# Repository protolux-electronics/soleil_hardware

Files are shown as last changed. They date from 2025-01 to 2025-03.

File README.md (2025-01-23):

# Soleil Hardware

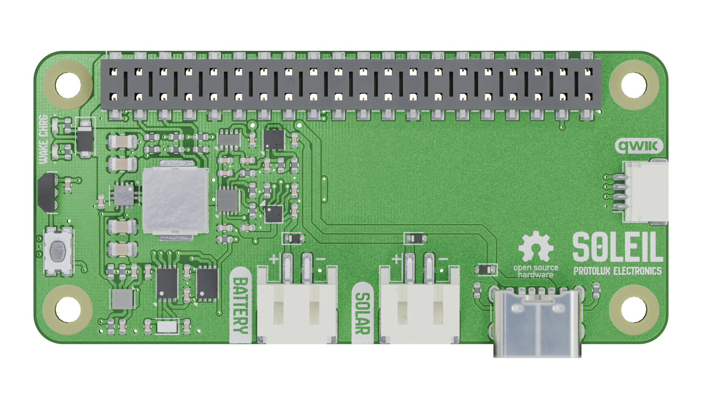
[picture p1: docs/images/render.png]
Soleil rendering

 
Soleil is a multi-functional solar charger and smart power management board for Rasbperry Pi. It has multiple use cases:

- **Off-grid**: power your project and simultaneously charge a single cell LiPo battery with a solar panel, up to 10W/16V.
- **Uninterruptible power supply**: Use a standard USB-C cable to power your Pi. In the case of a power outage, the power supply will automatically swap over to the backup battery without missing a beat.
- **Low power sleep mode**: completely cut off power to the Raspberry Pi for a duration of time. An onboard real-time clock will wake your project at the exact second you specify, up to one year in the future.

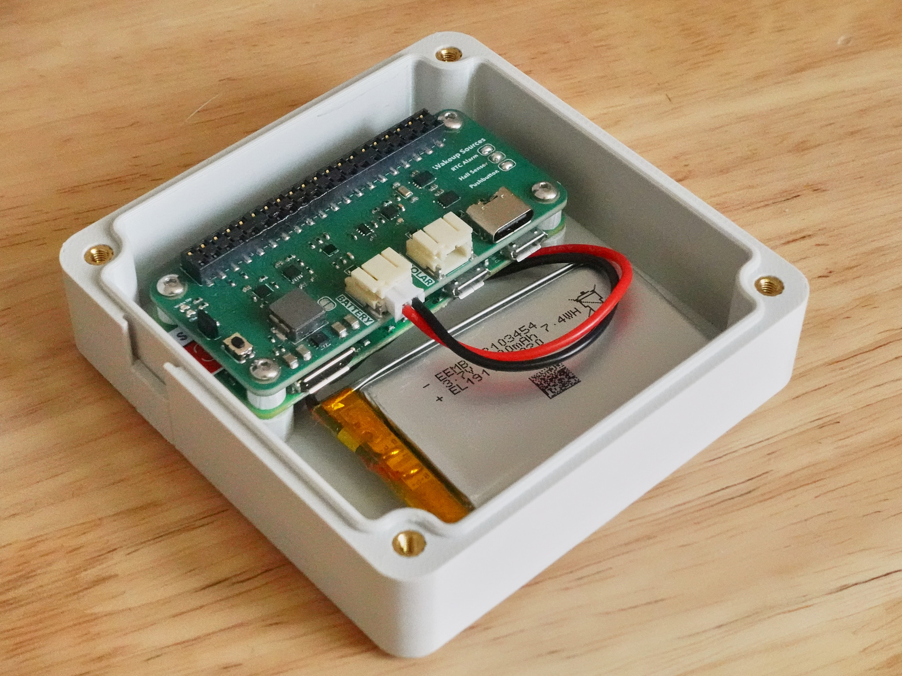
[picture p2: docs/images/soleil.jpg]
Soleil mounted in a 3D printed case


## Alternatives

Soleil takes inspiration from other boards on the market:

- [PiJuice Zero](https://uk.pi-supply.com/collections/pijuice/products/pijuice-zero)
- [WittyPi 4 Mini](https://www.uugear.com/product/witty-pi-4-mini/)
- [LiFePO4wered/Pi+](https://www.crowdsupply.com/silicognition/lifepo4wered-pi-plus)

Soleil is different, as it combines both the smart power management features with solar battery charging, up to 16V. In low power mode, Soleil only draws 15uA, making it a great choice for projects such as weather stations, IoT sensors, wildlife cameras, and more. Additionally, Soleil doesn't have a microcontroller onboard, and thus doesn't require firmware. It makes it just a little bit easier to hack on without requiring specialized programming hardware.

Additionally, Soleil is completely open hardware, build with KiCad. You can hack the hardware, modify the design to add your own sensors, or customize it to your liking. Supporting Soleil means supporting Open Source Hardware - an initiative that benefits all of us.

## Additional Features

Soleil includes a battery fuel gauge IC to get accurate state of charge estimations. There are also two manual wakeup sources - a pushbutton and a hall-effect switch. You may replace the hall effect switch with any open-drain sensor or circuit to trigger wakeup. Finally, Soleil features an ATECC608A security chip to provide first-class support for [NervesHub](https://nerves-hub.org), a firmware update management tool for Nerves-powered devices. 

See the block diagram below for an understanding of the connectivity of each of Soleil's components:

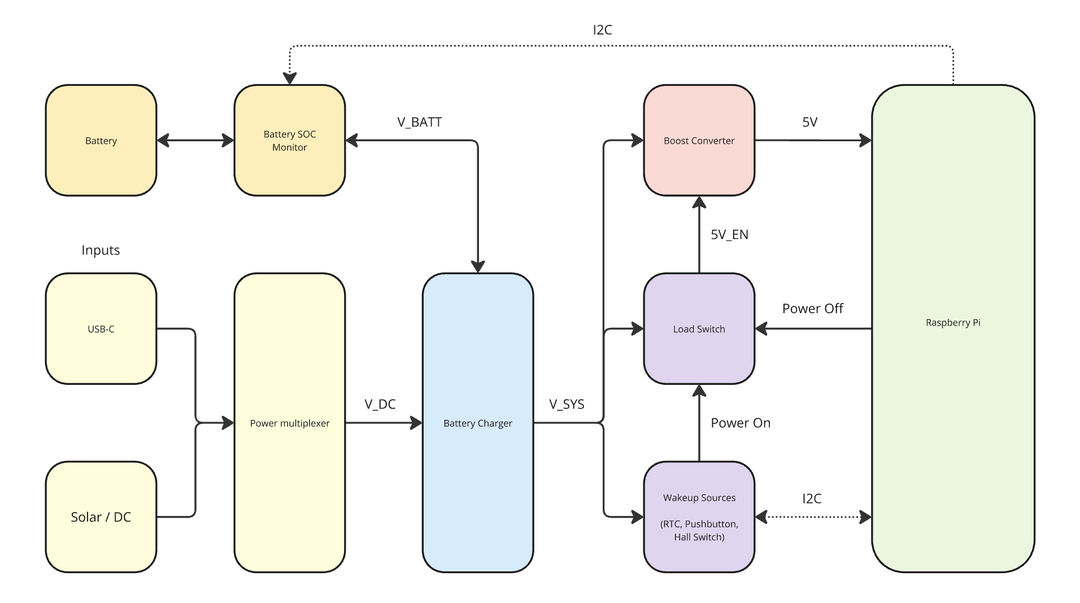
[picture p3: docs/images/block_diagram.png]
Block diagram


## Software

The official software library is available in the [Soleil repository](https://github.com/protolux-electronics/soleil). Soleil was specifically designed for use with the [Nerves Framework](https://nerves-project.org). See the [documentation](https://hexdocs.pm/soleil) for more information.

## Protolux Electronics

Soleil was designed by Protolux Electronics. We're a tiny team of passionate engineers, creatives, and designers based in Luxembourg.

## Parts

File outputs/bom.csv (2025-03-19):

Reference | Value | Footprint | Qty | DNP | LCSC | MPN
C1,C4 | 6p | Capacitor_SMD:C_0402_1005Metric | 2 |  | C437444 | GCM1555C1H6R0DA16D
C2,C3,C5,C6,C7,C8,C9,C10,C11 | 100n | Capacitor_SMD:C_0402_1005Metric | 9 |  | C71629 | GRM155R71C104KA88J
C12,C13,C14,C15 | 22u | Capacitor_SMD:C_0805_2012Metric | 4 |  | C98190 | CL21A226MOQNNNE
C16,C17,C18,C21,C24 | 1u | Capacitor_SMD:C_0402_1005Metric | 5 |  | C29266 | CL05A105KO5NNNC
C19,C20,C23 | 2u2 | Capacitor_SMD:C_0402_1005Metric | 3 |  | C72203 | GRM155R61E225ME15D
D1 | ESD5Z24 | Diode_SMD:D_SOD-523 | 1 |  | C23380859 | ESD5Z24
D2,D5 | RED | LED_SMD:LED_0402_1005Metric | 2 |  | C779449 | XZMDK68W-2
D3,D4 | ESD5Z6.0 | Diode_SMD:D_SOD-523 | 2 |  | C2890110 | ESD5Z6.0T1G
D6 | 500mV @ 2A | Diode_SMD:D_SOD-123F | 1 |  | C2972823 | S-LMBR340FT1G
J1,J4 | S2B-PH-SM4 | gworkman_connector:JST_PH_01x02_SMT_Horizontal | 2 |  | C295747 | S2B-PH-SM4-TB
J2 | Raspberry_Pi | gworkman_connector:RaspberryPi_low_profile_HAT_connector | 1 |  | C2685112 | FH-00339
J3 | USB4125-GF-A | Connector_USB:USB_C_Receptacle_GCT_USB4125-xx-x_6P_TopMnt_Horizontal | 1 |  | C2874565 | USB4125-GF-A
J5 | SM04B-SRSS-TB | Connector_JST:JST_SH_SM04B-SRSS-TB_1x04-1MP_P1.00mm_Horizontal | 1 |  | C160404 | SM04B-SRSS-TB
L1 | 1u5 | gworkman_device:L_Vishay_IHLP-2525 | 1 |  | C845020 | IHLP2525CZER1R5M01
R1,R2,R3,R4,R5,R8 | 5k1 | Resistor_SMD:R_0402_1005Metric | 6 |  | C105872 | RC0402FR-075K1L
R6,R7,R11,R16,R19,TH1 | 10k | Resistor_SMD:R_0402_1005Metric | 6 |  | C60490,C77131 | NCP15XH103F03RC,RC0402FR-0710KL
R9 | 750k | Resistor_SMD:R_0402_1005Metric | 1 |  | C137937 | RC0402FR-07750KL
R10 | 133k | Resistor_SMD:R_0402_1005Metric | 1 |  | C327374 | RC0402FR-07133KL
R13 | 13k | Resistor_SMD:R_0402_1005Metric | 1 |  | C138057 | RC0402FR-0713KL
R14,R20,R21 | 1M2 | Resistor_SMD:R_0402_1005Metric | 3 |  | C226867 | AC0402FR-071M2L
R15 | 200k | Resistor_SMD:R_0402_1005Metric | 1 |  | C114763 | RC0402FR-07200KL
R18 | 1k | Resistor_SMD:R_0402_1005Metric | 1 |  | C105637 | RC0402JR-071KL
SW1 | SW_Push | Button_Switch_SMD:SW_Push_1P1T_NO_CK_KMR2 | 1 |  | C221678 | KMR223GLFG
U1 | MCP7940N-xMNY | Package_DFN_QFN:DFN-8-1EP_3x2mm_P0.5mm_EP1.36x1.46mm | 1 |  | C623889 | MCP7940NT-I/MNY
U2 | XC6192B | gworkman_power:USP-8B06 | 1 |  | C2442364 | XC6192BANNER-G
U3 | LM66200 | gworkman_power:Texas_DRL0008A_SOT-583 | 1 |  | C3235556 | LM66200DRLR
U4 | ATECC608A-MAHDA | Package_DFN_QFN:DFN-8-1EP_3x2mm_P0.5mm_EP1.3x1.5mm | 1 |  | C616908 | ATECC608A-MAHDA-S
U5 | DRV5032FC | Package_TO_SOT_THT:TO-92Flat | 1 |  | C2866256 | DRV5032FCLPGM
U6 | MP3423 | gworkman_power:MPS_PowerQFN-14_2x2mm | 1 |  | C2682483 | MP3423GG-Z
U7 | BQ25185 | gworkman_power:Texas_DLH0010A_WSON-10 | 1 |  | C19725033 | BQ25185DLHR
U8 | TLV76701DRVx | Package_SON:WSON-6-1EP_2x2mm_P0.65mm_EP1x1.6mm_ThermalVias | 1 |  | C2863998 | TLV76701DRVR
U9 | BQ27427 | Package_BGA:Texas_DSBGA-9_1.62x1.58mm_Layout3x3_P0.5mm | 1 |  | C6075475 | BQ27427YZFR
Y1 | 32.768kHz | Crystal:Crystal_SMD_2012-2Pin_2.0x1.2mm | 1 |  | C3015107 | ECS-.327-7-12-TR

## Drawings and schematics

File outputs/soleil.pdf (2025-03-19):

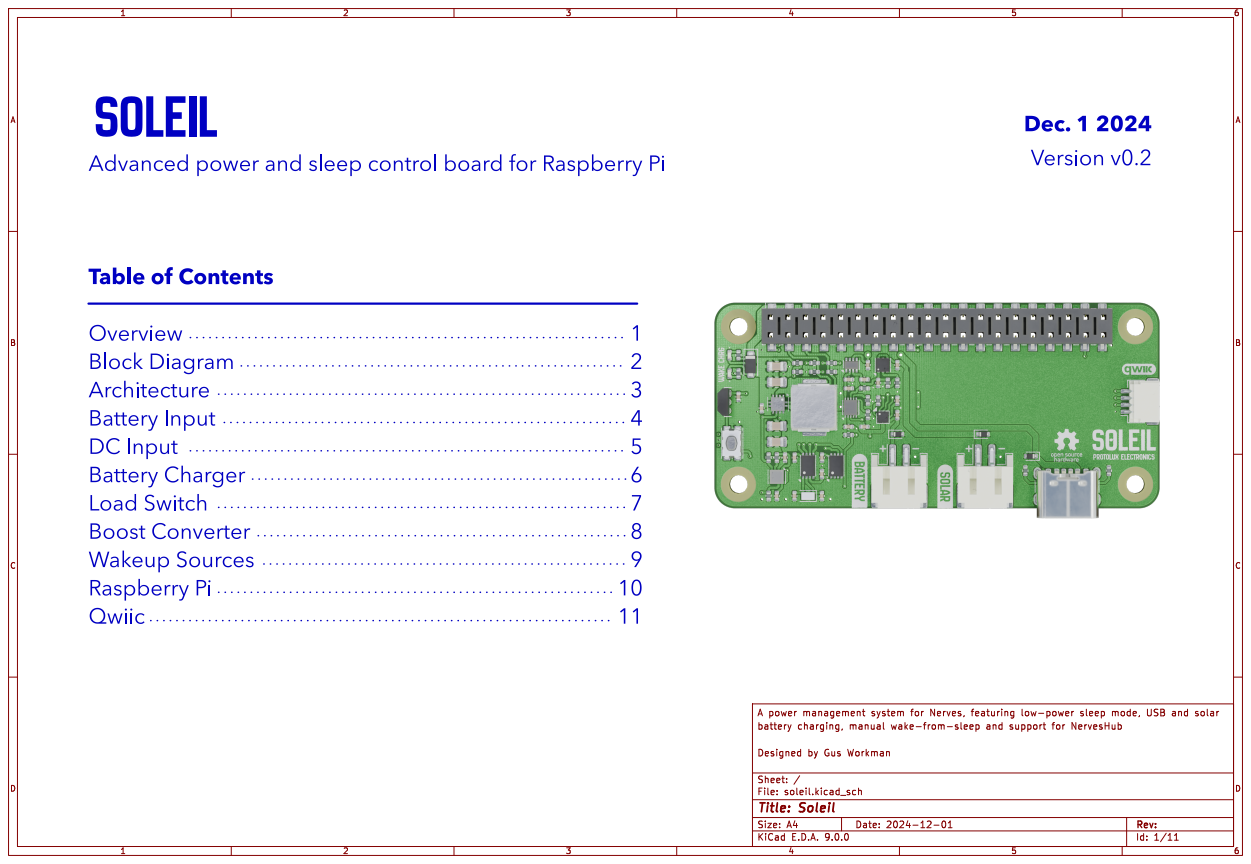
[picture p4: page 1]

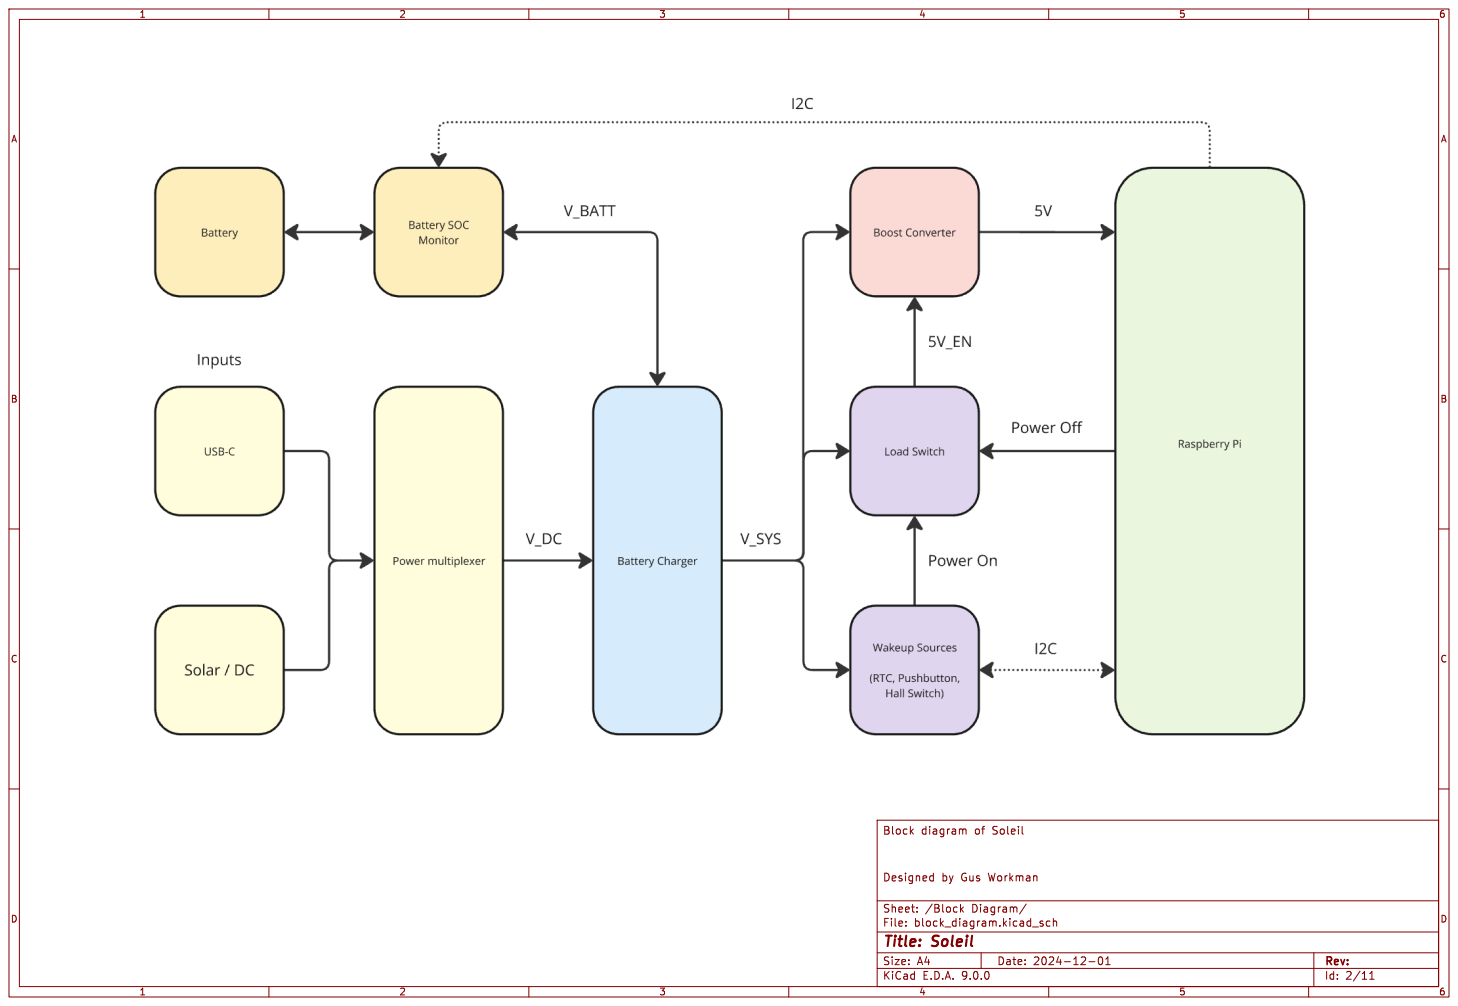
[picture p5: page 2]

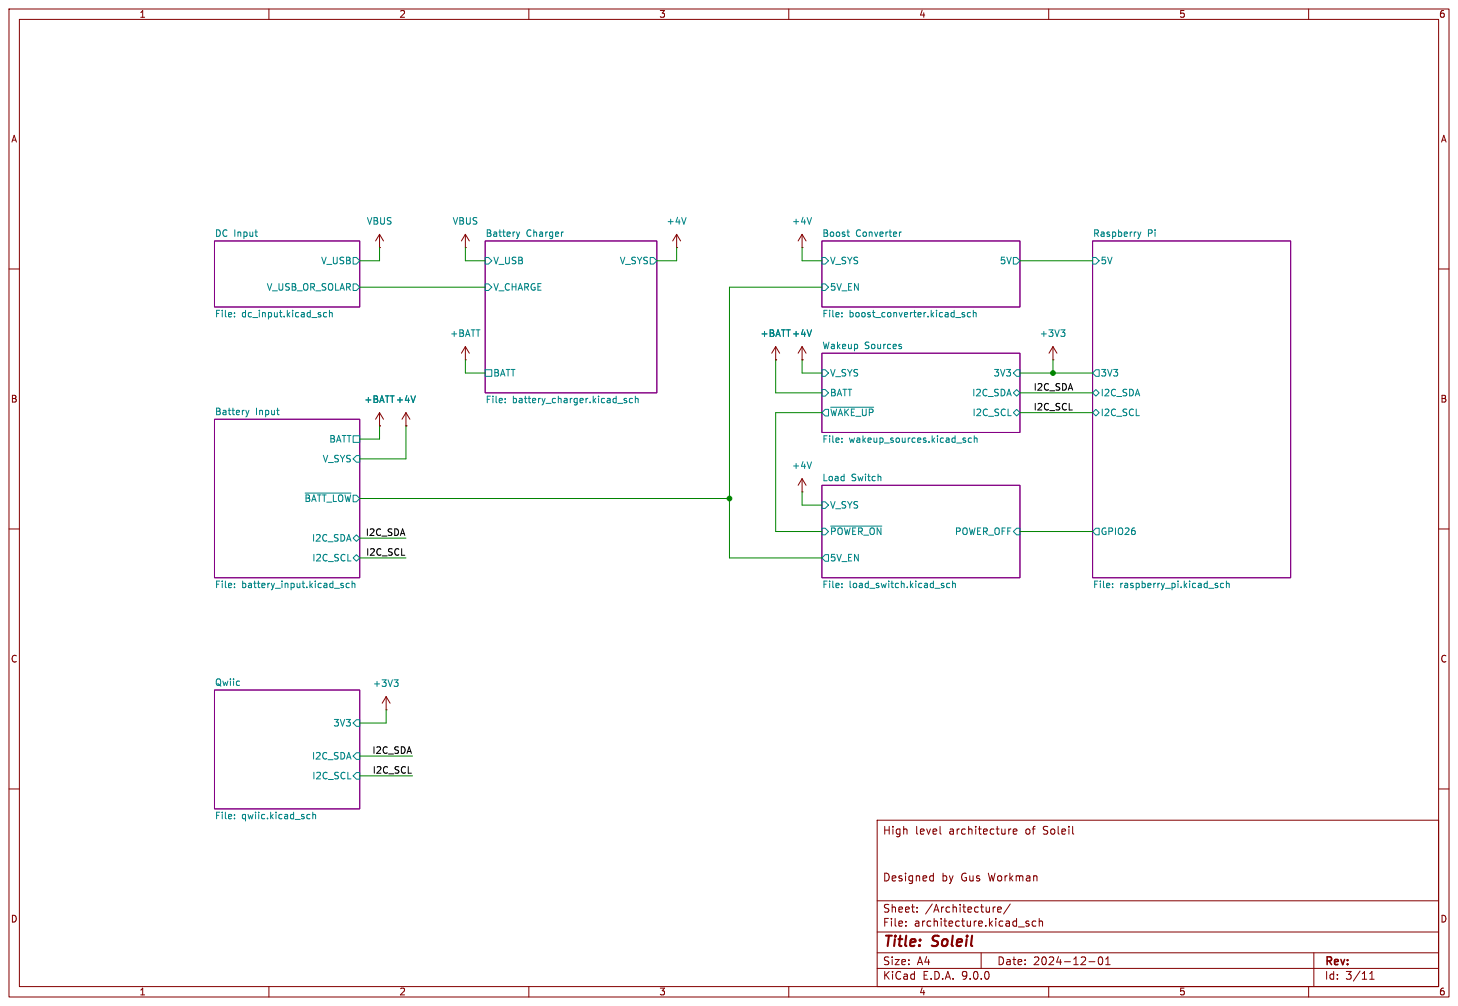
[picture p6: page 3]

Boost Converter File: boost_converter.kicad_sch ~{BATT_LOW} BATT

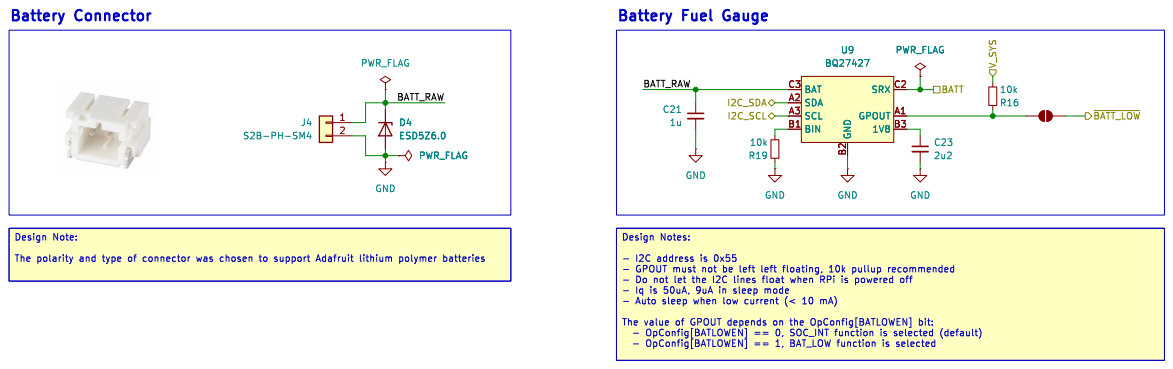
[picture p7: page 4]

- Do not let the I2C lines float when RPi is powered off - Iq is 50uA, 9uA in sleep mode

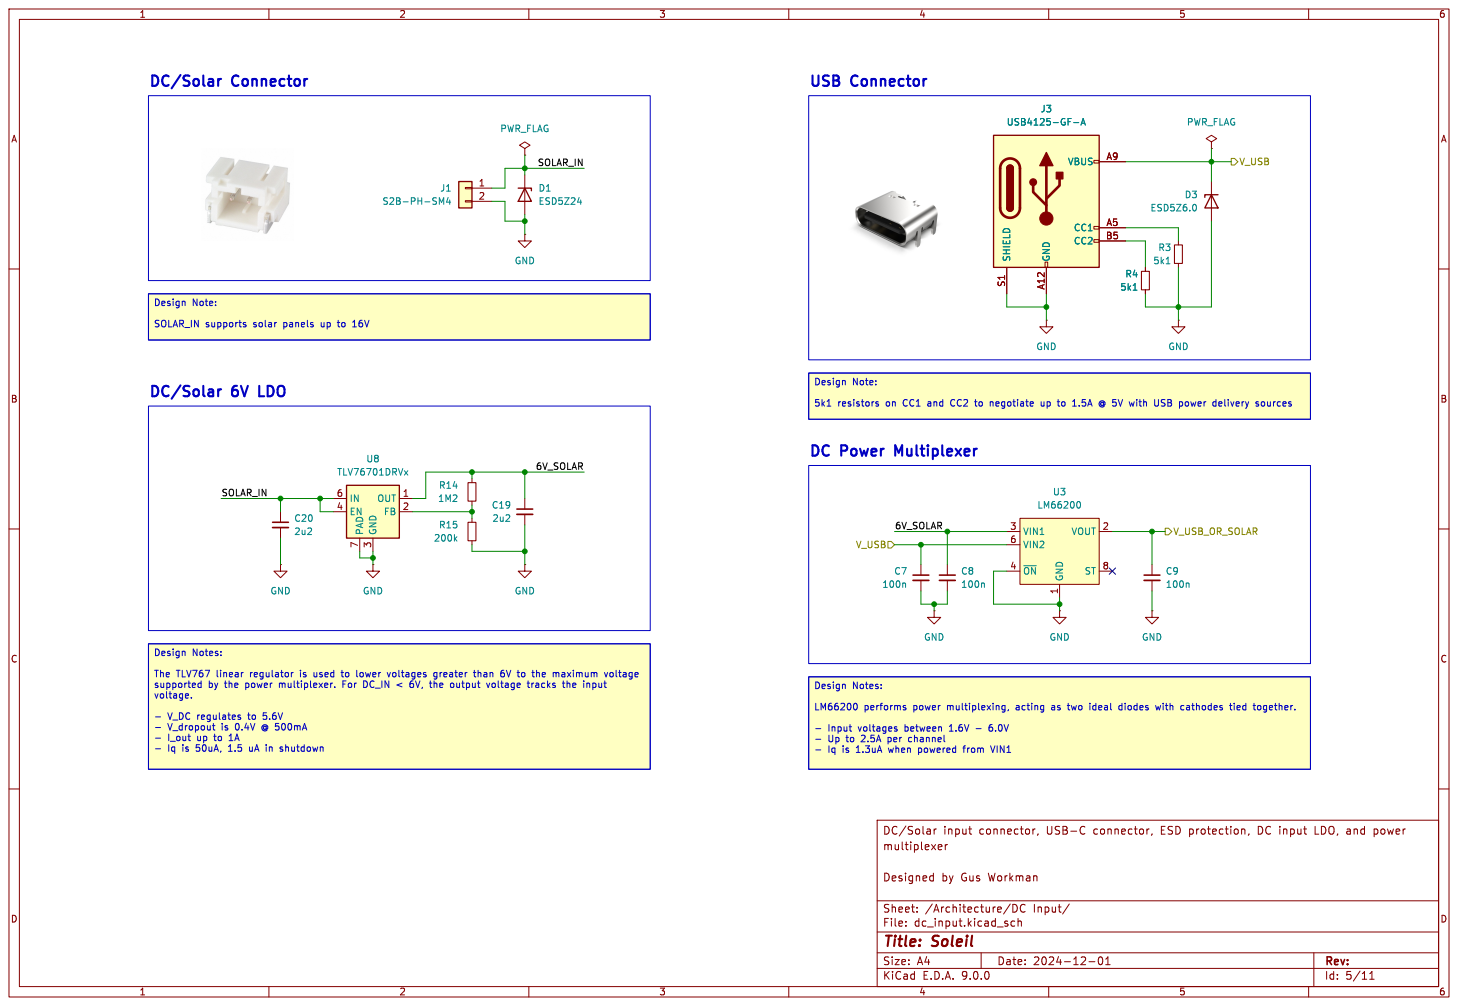
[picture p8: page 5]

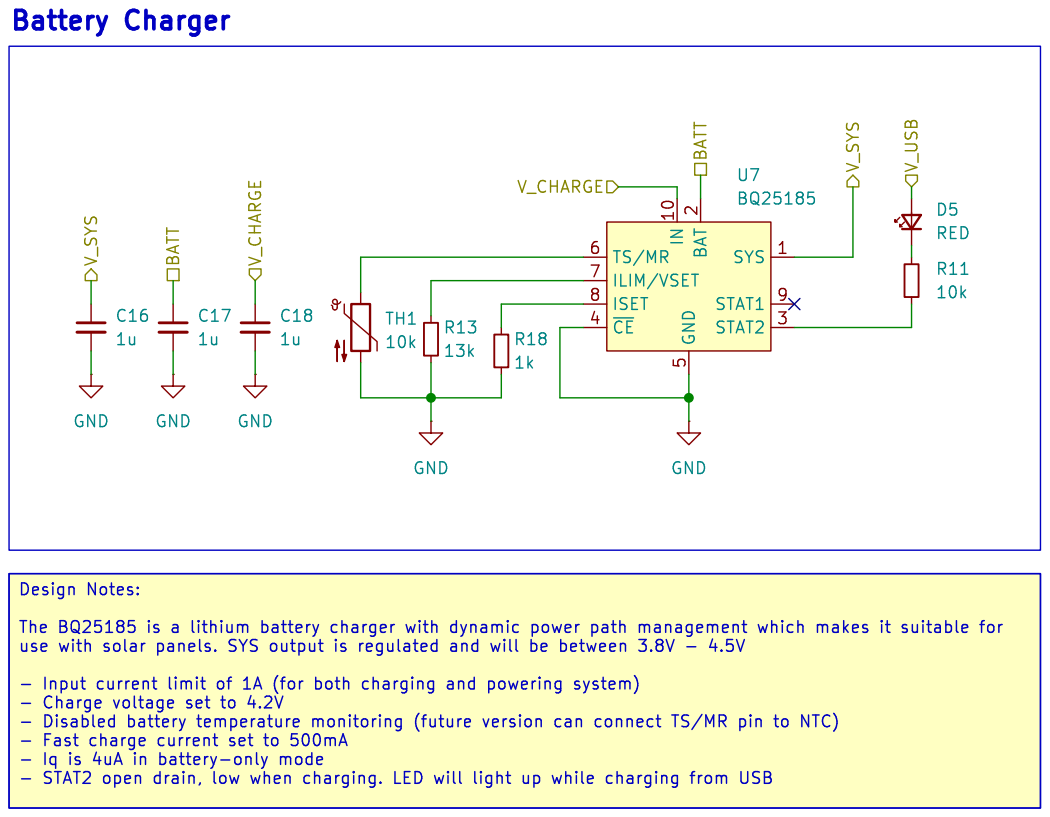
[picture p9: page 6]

- Charge voltage set to 4.2V
- Fast charge current set to 500mA

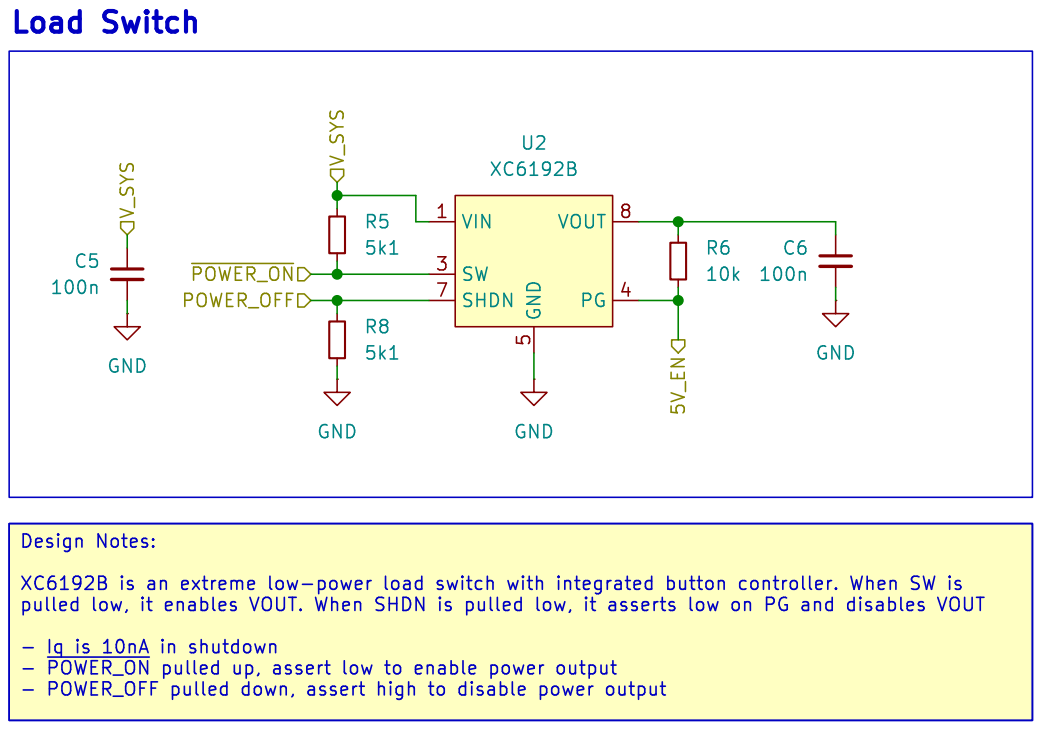
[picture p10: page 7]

- Iq is 10nA in shutdown

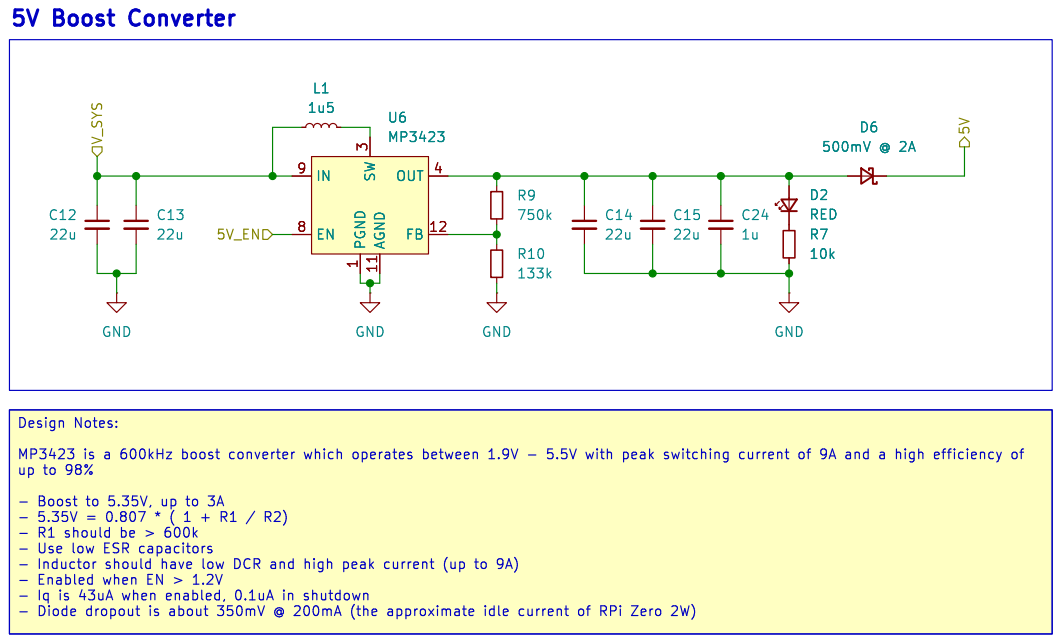
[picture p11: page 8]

3 AGND 11 OUT 4 FB 12 U6 MP3423 GND

- Boost to 5.35V, up to 3A
- R1 should be > 600k
- Use low ESR capacitors
- Enabled when EN > 1.2V
- Iq is 43uA when enabled, 0.1uA in shutdown

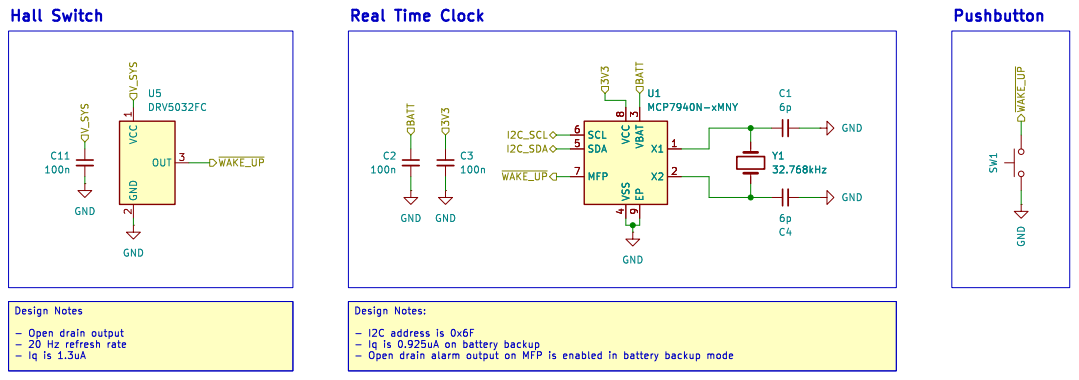
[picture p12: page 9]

- Open drain output - 20 Hz refresh rate

- Iq is 0.925uA on battery backup

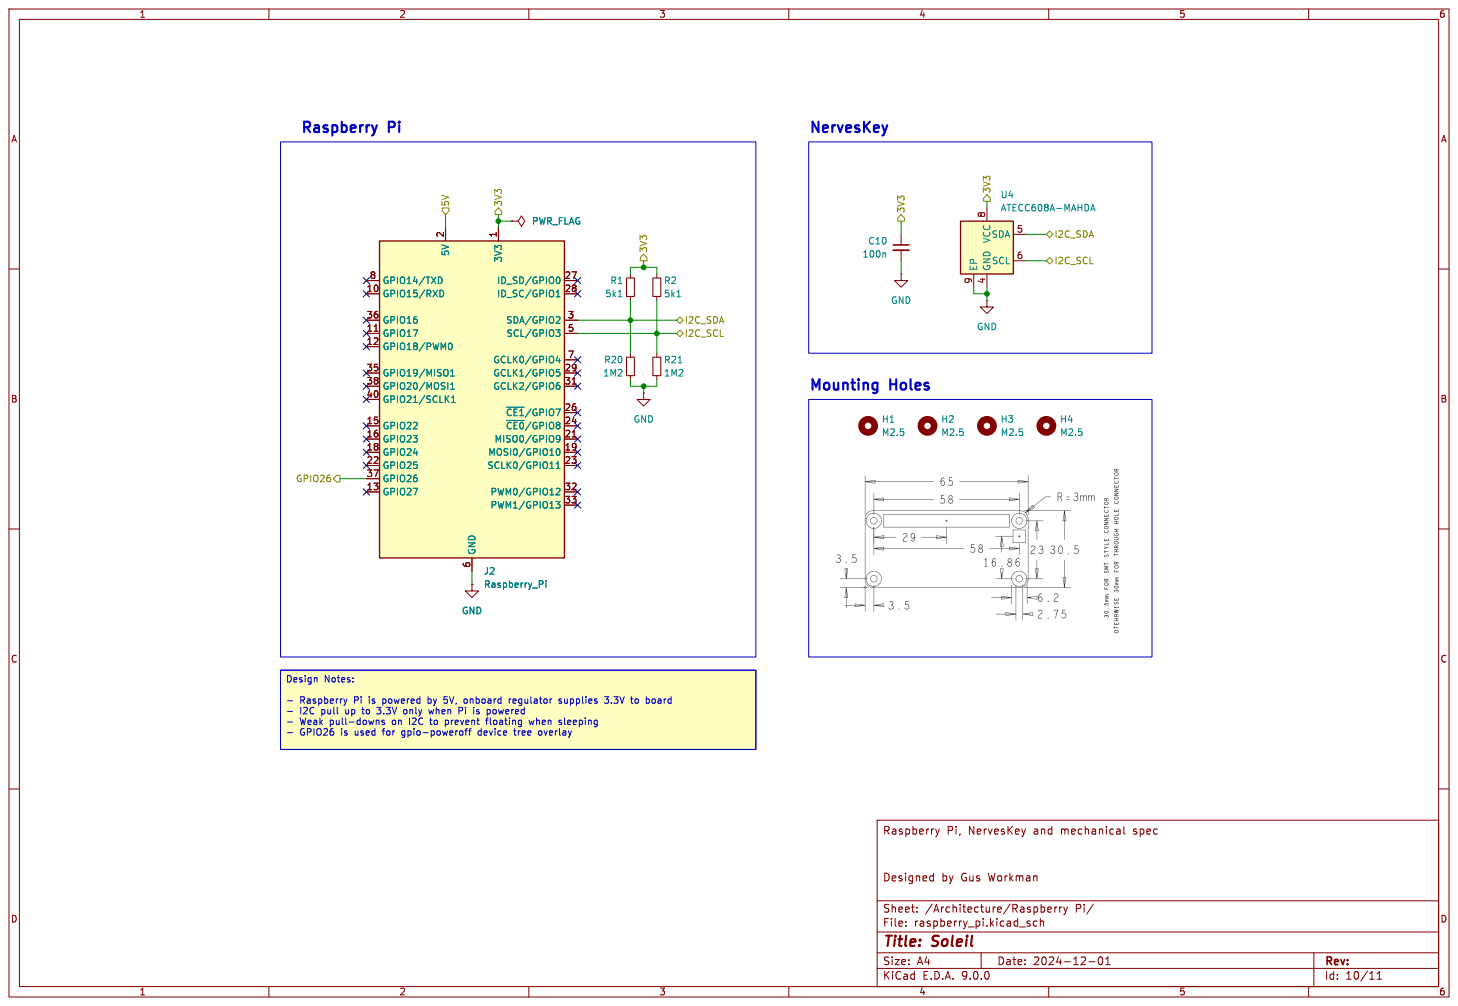
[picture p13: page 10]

- I2C pull up to 3.3V only when Pi is powered

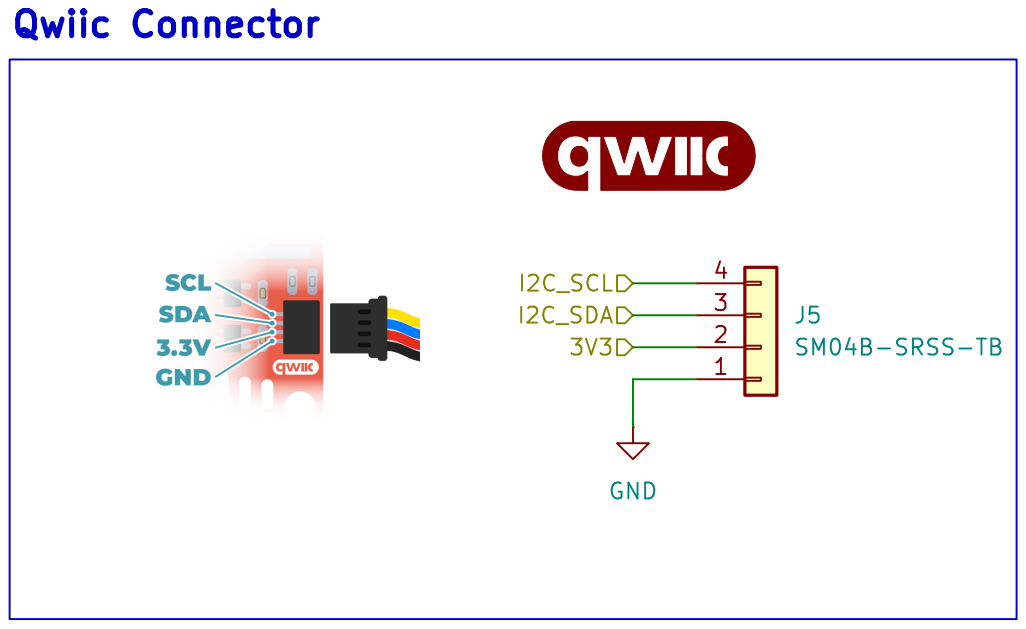
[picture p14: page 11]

Id: 11/11 Title: Soleil File: qwiic.kicad_sch Sheet: /Architecture/Qwiic/

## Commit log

2024-08-15 create basic schematic
    [soleil_powerpack.kicad_sch]
2024-08-23 finish schematic and layout
    [soleil_powerpack.kicad_pcb, soleil_powerpack.kicad_sch]
2024-08-29 update layout
    [soleil_powerpack.kicad_pcb]
2024-08-29 add gerbers and updated blender
    [soleil_powerpack-B_Cu.gbr, soleil_powerpack-B_Mask.gbr, soleil_powerpack-B_Paste.gbr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]
2024-09-21 update schematic and PCB to include LDO, battery fuel gauge, etc; ordered at PCBWay
    [power.kicad_sch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]
2024-10-17 add digikey part numbers
    [bom.csv, power.kicad_sch, soleil.kicad_sch]
2024-10-17 clean and plot schematic to pdf
    [power.kicad_sch, soleil.kicad_sch]
2024-10-17 add readme
    [power.kicad_sch, soleil.kicad_pcb]
2024-12-03 update schematic for publish
    [architecture.kicad_sch, battery_charger.kicad_sch, battery_input.kicad_sch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]
2024-12-17 add qwiic connector
    [architecture.kicad_sch, qwiic.kicad_sch, soleil.kicad_sch]
2024-12-17 wip routing
    [soleil.kicad_pcb]
2025-01-23 finish all schematic changes
    [battery_input.kicad_sch, boost_converter.kicad_sch, load_switch.kicad_sch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]
2025-01-23 finish routing v0.2
    [soleil.kicad_pcb]
2025-01-23 update gerbers and outputs
    [battery_charger.kicad_sch, bom.csv, boost_converter.kicad_sch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]
2025-03-19 update to kicad 9.0
    [architecture.kicad_sch, battery_charger.kicad_sch, battery_input.kicad_sch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]
2025-03-19 add jobset file, update outputs
    [battery_input.kicad_sch, block_diagram.kicad_sch, bom.csv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]
